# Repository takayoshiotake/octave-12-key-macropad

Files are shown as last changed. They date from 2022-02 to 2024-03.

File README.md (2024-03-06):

# Octave

[][cc-by-sa]

The Octave is a 12-key macropad.
It is primarily designed to be a compact keyboard with support for 12 function keys (F1 - F12).

## Status

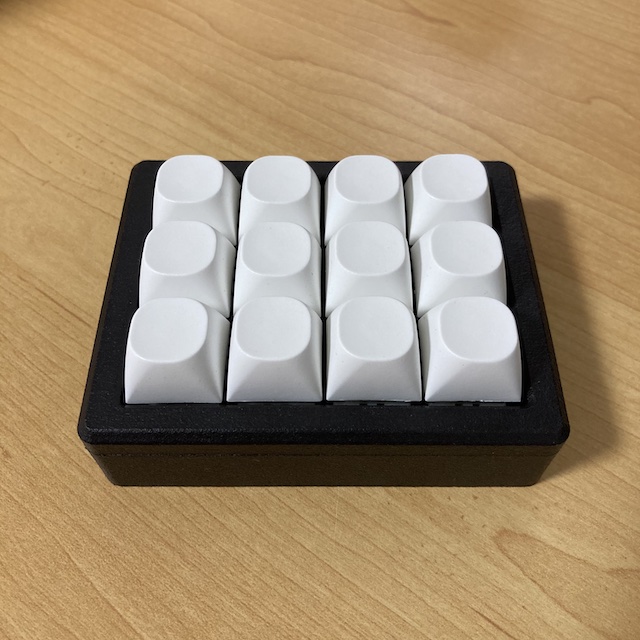
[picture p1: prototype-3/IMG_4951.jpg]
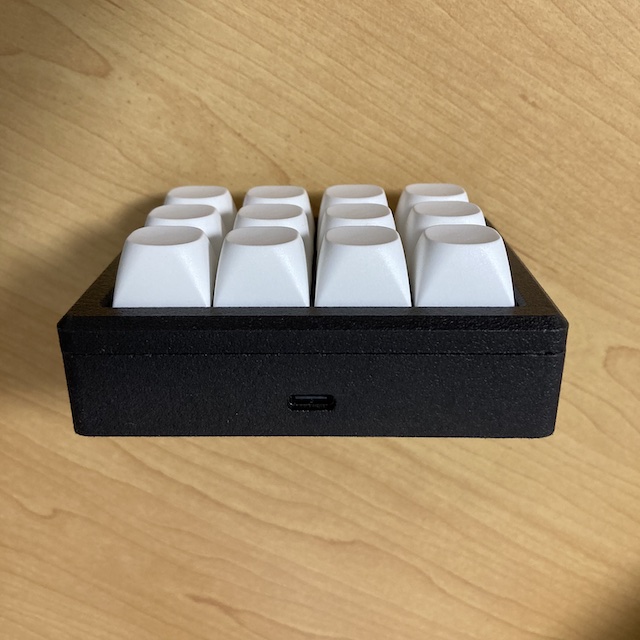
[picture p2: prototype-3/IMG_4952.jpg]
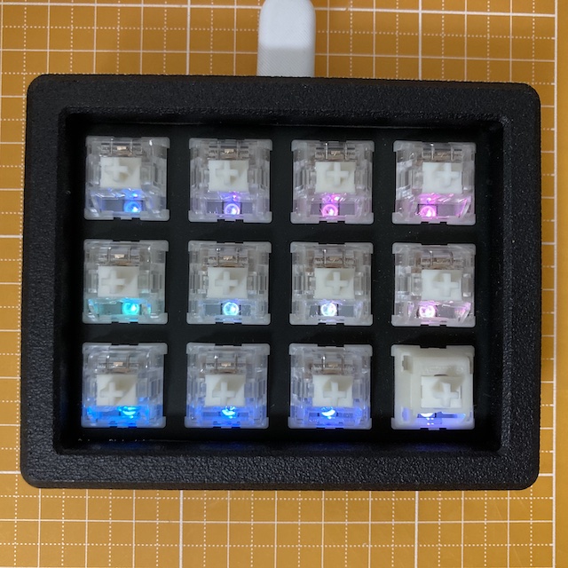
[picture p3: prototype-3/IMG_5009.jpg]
  

- [x] prototype-3.1: Upgrade with LEDs under keys
  - [x] LED Animation
  - [x] PCB: OK!
- [x] prototype-3: Simple design
  - [x] Enclosure: OK!
  - [x] Test: OK!
  - [x] PCB: OK!
- [x] prototype-2: Custom MCU board
  - [x] Consideration
  - [x] Test
  - [x] PCB
- [x] prototype-1

## Specifications

- USB-C (USB2.0, HID)
  - 🔗 <https://pid.codes/1209/8CAE/>
- Hot-swap sockets for MX compatible switches
- Programmable firmware (CircuitPython)

## Layout

📄 [layout/keyboard-layout.png](layout/keyboard-layout.png) (rev.6)

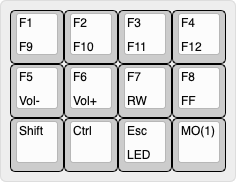
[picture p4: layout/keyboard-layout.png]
keyboard layout


- 12 function keys (F1 - F12)

**RAW data for Keyboard Layout Editor v0.15:**

📄 [layout/keyboard-layout.rawdata.json](layout/keyboard-layout.rawdata.json)

```json
[{f:3},"F1\nF9","F2\nF10","F3\nF11","F4\nF12"],
["F5\nVol-","F6\nVol+","F7\nRW","F8\nFF"],
["Shift","Ctrl","Esc\nLED","MO(1)"]
```

- 🔗 [Keyboard Layout Editor](http://www.keyboard-layout-editor.com/)

## Schematic

📄 [electronics/Octave_Input_PCB.svg](electronics/Octave_Input_PCB.svg) (rev.6.1.2)

schematic svg

I have also designed a custom MCU circuit from prototype-2, the MCU is RP2040 and the software runs on CircuitPython built specifically for it.

📄 [electronics/Octave_Input_PCB/Octave_Input_PCB.kicad_sch](electronics/Octave_Input_PCB/Octave_Input_PCB.kicad_sch)

### Upgrade schematic with LEDs under keys

📄 [electronics/Octave_Input_LED_PCB.svg](electronics/Octave_Input_LED_PCB.svg) (rev.1.0.0)

led schematic svg

📄 [electronics/Octave_Input_PCB/Octave_Input_LED_PCB.kicad_sch](electronics/Octave_Input_PCB/Octave_Input_LED_PCB.kicad_sch)

## PCB

📄 [electronics/Octave_Input_PCB_3D.png](electronics/Octave_Input_PCB_3D.png) (rev.6.1.3)

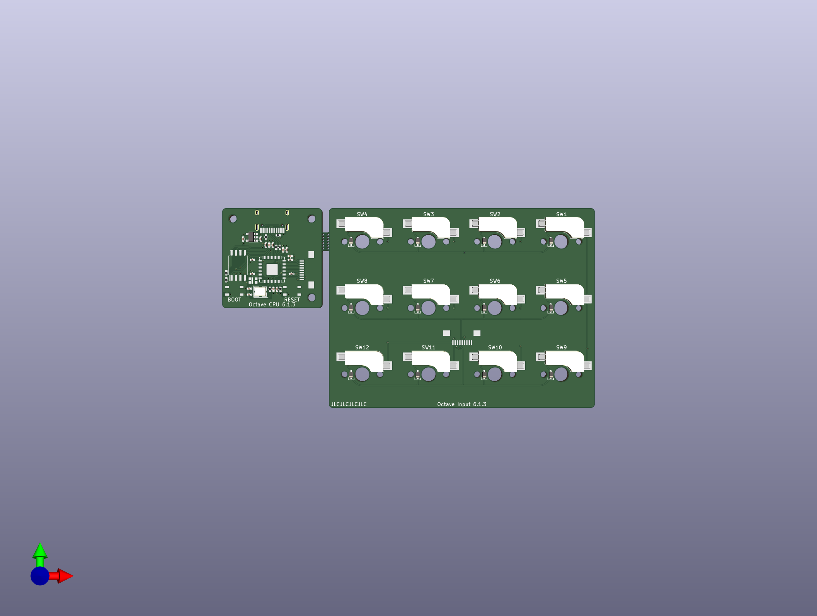
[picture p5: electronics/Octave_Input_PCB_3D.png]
pcb 3d png


📄 [electronics/Octave_Input_PCB/Octave_Input_PCB.kicad_pcb](electronics/Octave_Input_PCB/Octave_Input_PCB.kicad_pcb)

### Upgrade PCB with LEDs under keys

📄 [electronics/Octave_Input_LED_PCB_3D.png](electronics/Octave_Input_LED_PCB_3D.png) (rev.1.0.0)

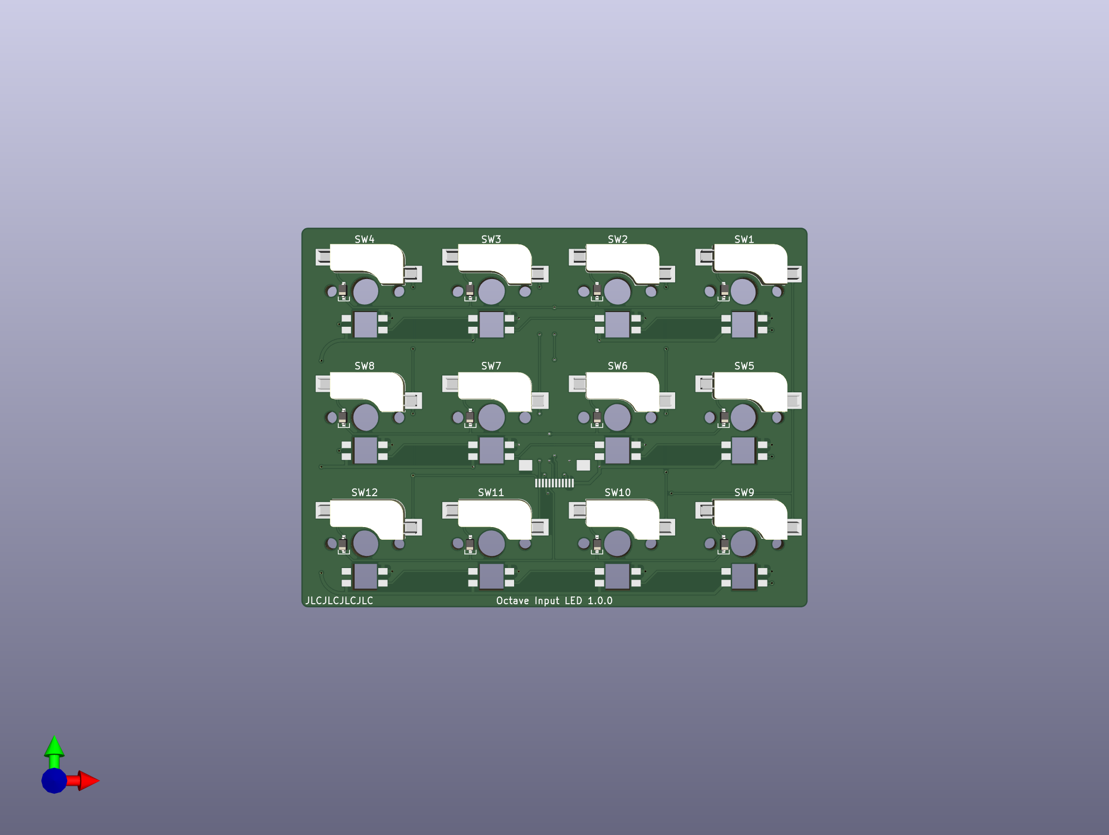
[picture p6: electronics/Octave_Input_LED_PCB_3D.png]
led pcb 3d png


📄 [electronics/Octave_Input_LED_PCB/Octave_Input_LED_PCB.kicad_pcb](electronics/Octave_Input_LED_PCB/Octave_Input_LED_PCB.kicad_pcb)

## CircuitPython

Software for the Octave (prototype-2, prototype-3) runs on CircuitPython.

**Latest:**

- 🔗 [adafruit/circuitpython](https://github.com/adafruit/circuitpython)
  - 🔗 <https://github.com/adafruit/circuitpython/tree/main/ports/raspberrypi/boards/takayoshiotake_octave_rp2040>
- 🔗 [Built UF2](https://adafruit-circuit-python.s3.amazonaws.com/index.html?prefix=bin/takayoshiotake_octave_rp2040/)

**Older:**

- 🔗 [takayoshiotake/circuitpython:7.3.x-board-octave-rp2040](https://github.com/takayoshiotake/circuitpython/tree/7.3.x-board-octave-rp2040)
  - 🔗 <https://github.com/takayoshiotake/circuitpython/tree/c3b4d05dc04d74c6229506215eae799fb23f37ce/ports/raspberrypi/boards/takayoshiotake_octave_rp2040>

- How to build:
  - 🔗 <https://learn.adafruit.com/building-circuitpython/build-circuitpython>
  - 🔗 <https://github.com/takayoshiotake/circuitpython/blob/c3b4d05dc04d74c6229506215eae799fb23f37ce/BUILDING.md>

## Plate

📄 [mechanics/Octave_Plate_3D.png](mechanics/Octave_Plate_3D.png) (rev.1.0.3)

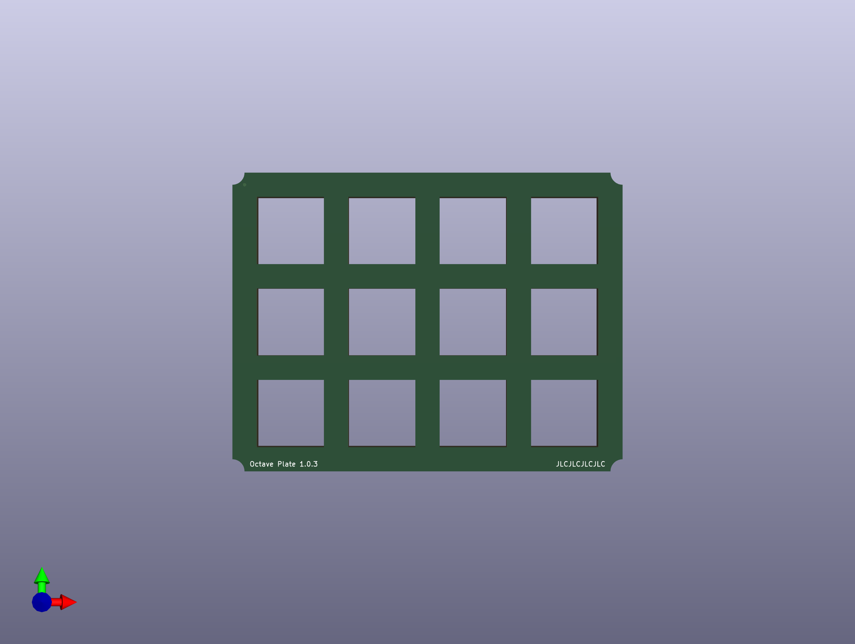
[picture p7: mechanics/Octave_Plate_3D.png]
plate 3d png


📄 [mechanics/Octave_Plate/Octave_Plate.kicad_pcb](mechanics/Octave_Plate/Octave_Plate.kicad_pcb)

## Enclosure

- 📄 [mechanics/Octave_Enclosure-Case.stl](mechanics/Octave_Enclosure-Case.stl) (rev.1.0.0)
- 📄 [mechanics/Octave_Enclosure-Top Frame.stl](mechanics/Octave_Enclosure-Top%20Frame.stl) (rev.1.0.0)

## BOM & Software

🏷 [prototype-3-pcb](https://github.com/takayoshiotake/octave-12-key-macropad/releases/tag/prototype-3-pcb)

| Material | Unit | Designator | Note | JLCPCB Part # |
|-|-:|-|-|-|
| Octave CPU PCB rev.6.1.3 | 1 | n/a | JLCPCB |
| Octave Input PCB rev.6.1.3 *[2]* | 1 | n/a | JLCPCB |
| Octave Plate rev.1.0.3 | 1 | n/a | JLCPCB, Alminium PCB (t=1.6mm) |
| 0151660120 | 1 | n/a | Molex 0.50mm pitch FFC, Type D, 50.80mm, 12 circuits |
| CPG151101S11-2 | 12 | SW1-12 *[2]* | Kailh®︎ hot swap socket (White) |
||
| Octave Enclosure Case rev.1.0.0 | 1 | n/a | JLCPCB, 3D printing (MJF), PA12-HP Nylon |
| Octave Enclosure Top Frame rev.1.0.0 | 1 | n/a | JLCPCB, 3D printing (MJF), PA12-HP Nylon |
| PORON | 4 | n/a | 78mm x 2.5mm (t=1.5mm) |
| PORON | 4 | n/a | 59mm x 2.5mm (t=1.5mm) |
| Screw M2 5mm | 1 | n/a | Hirosugi B-0205 |
| Screw M2 8mm | 4 | n/a | Hirosugi B-0208 |
| Insert nut M2 | 4 | n/a | Hirosugi HSB-203030Z |
| Nut M2 | 1 | n/a | Hirosugi BNT-02-2 |
| Washer M2 | 1 | n/a | Hirosugi BW-0243-03 |
||
| 30pF 0402 | 2 | C15, C16 | PCBA | C1570 |
| 100nF 0402 | 10 | C5-14 | PCBA | C307331 |
| 1uF 0402 | 2 | C3, C4 | PCBA | C52923 |
| 10uF 0402 | 2 | C1, C2 | PCBA | C15525 |
| 1N4148WS | 12 | D1-12 *[2]* | PCBA | C2128 |
| HRO_TYPE-C-31-M-12 | 1 | J1 | PCBA, USB Connector (Type-C) | C165948 |
| JUSHUO_AFC01-S12FCC-00 | 2 | J2, J3 *[2]* | PCBA, FFC Connector (0.50mm pitch, 12 circuits) | C262268 |
| 27Ω 0402 | 2 | R3, R4 | PCBA | C352446 |
| 1KΩ 0402 | 2 | R7, R8 | PCBA | C11702 |
| 5.1KΩ 0402 | 2 | R1, R2 | PCBA | C25905 |
| 10KΩ 0402 | 2 | R5, R6 | PCBA | C25744 |
| AP2112K-3.3 | 1 | U1 | PCBA | C51118 |
| Raspberry Pi RP2040 | 1 | U2 | PCBA | C2040 |
| W25Q64JVSSIQ | 1 | U3 | PCBA | C179171 |
| 12MHz Crystal Resonator SMD-3225 | 1 | Y1 | PCBA, YSX221SL | C9002 |
| SKRPANE010 | 2 | SW21, SW22 | PCBA, Alps Alpine tactile switch | C470426 |
||
| WS2812C-2020-V1 | 1 | LED1 *[1]* | PCBA, NeoPixel | C2976072 |

MEMO: *[1]* To reduce costs, I did not assemble LED1 with PCBA.
MEMO: *[2]* Can be replaced with upgrade parts.

Upgrade parts:

| Material | Unit | Designator | Note | JLCPCB Part # |
|-|-:|-|-|-|
| Octave Input LED PCB rev.1.0.0 | 1 | n/a | JLCPCB |
| CPG151101S11-2 | 12 | SW1-12 | Kailh®︎ hot swap socket (White) |
||
| 1N4148WS | 12 | D1-12 | PCBA | C2128 |
| JUSHUO_AFC01-S12FCC-00 | 1 | J3 | PCBA, FFC Connector (0.50mm pitch, 12 circuits) | C262268 |
||
| WS2812B-Mini-V3 | 12 | LED201-0212 | NeoPixel |

- Octave CPU PCB rev.6.1.3, Octave Input PCB rev.6.1.3 (PCBA)

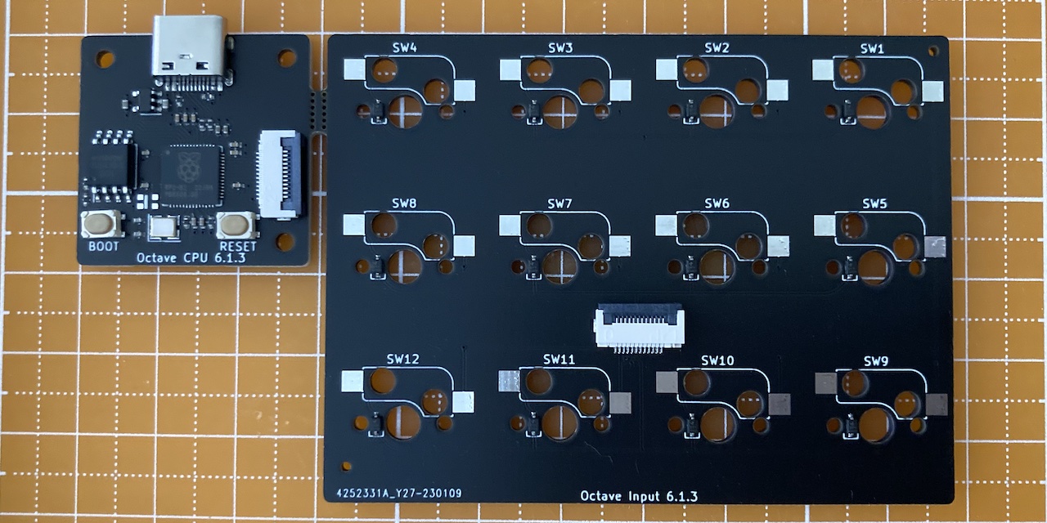
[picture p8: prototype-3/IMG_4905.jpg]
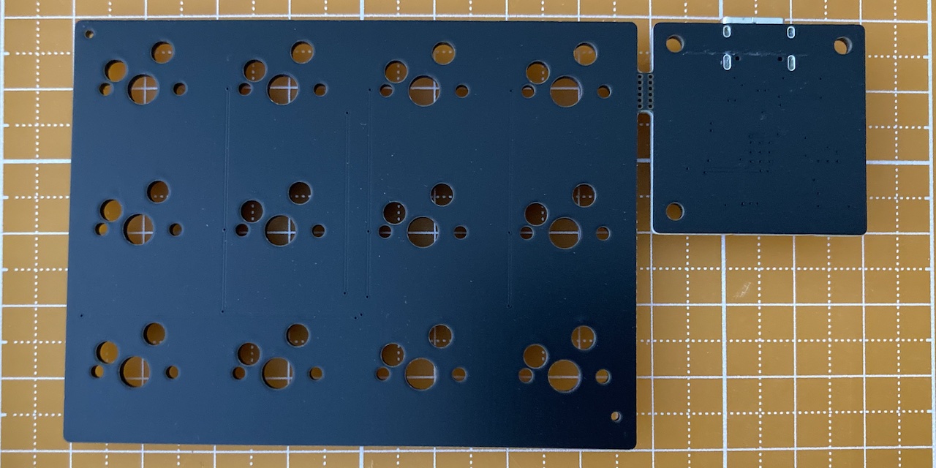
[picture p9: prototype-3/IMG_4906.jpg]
     

- Octave Input LED PCB rev.1.0.0 (Upgrade)

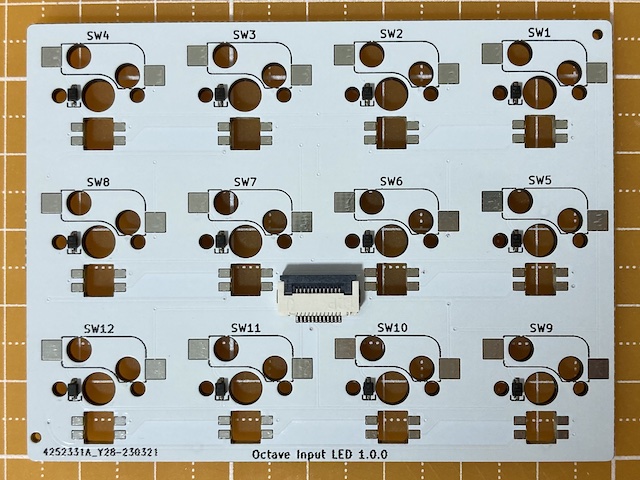
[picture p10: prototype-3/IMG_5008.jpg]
    

- Octave Plate rev.1.0.3

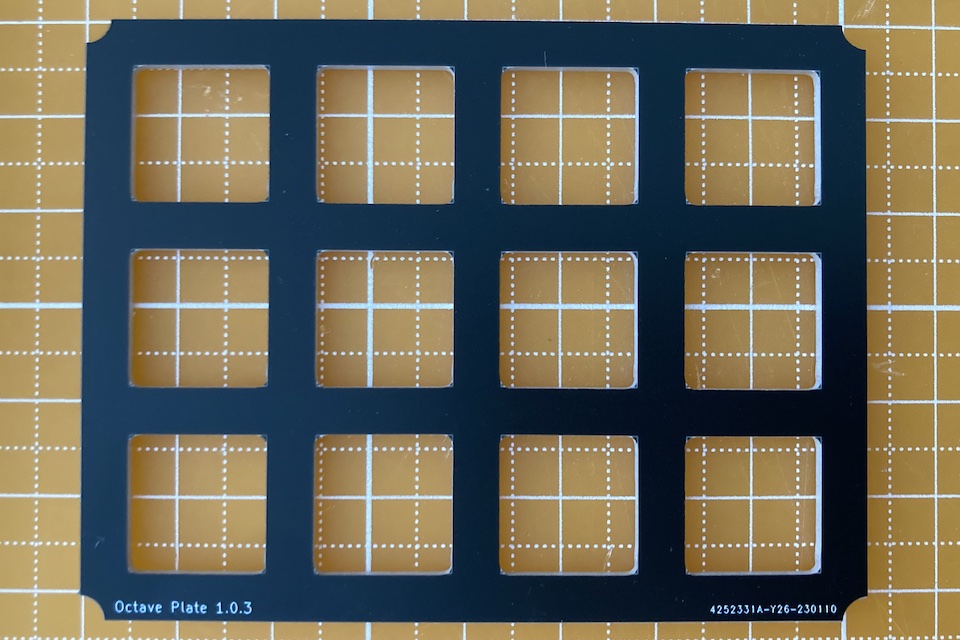
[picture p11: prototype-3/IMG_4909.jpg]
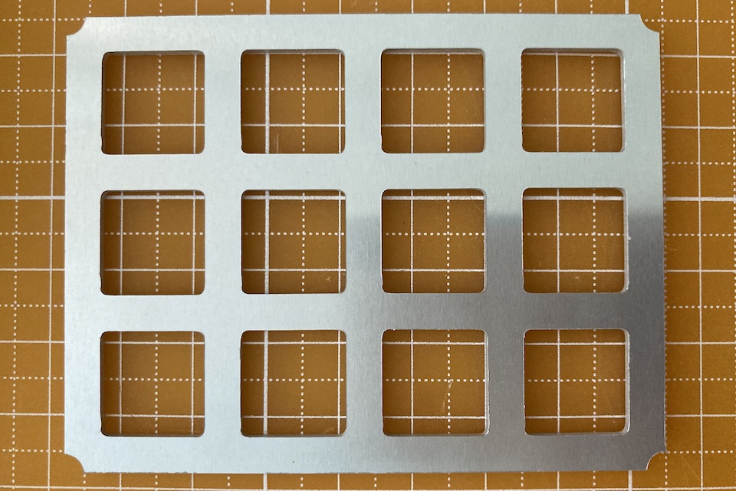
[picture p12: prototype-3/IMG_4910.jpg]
     

- Assembly

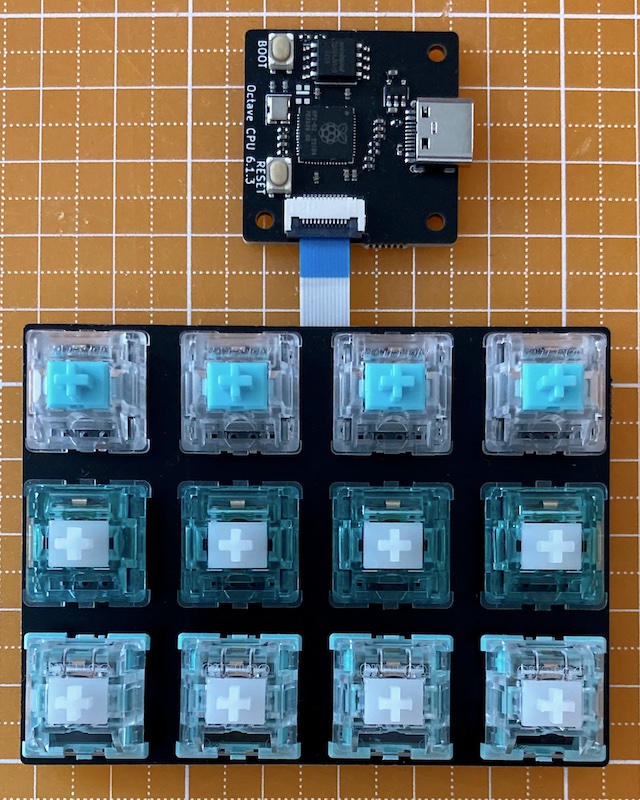
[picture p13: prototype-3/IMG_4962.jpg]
    
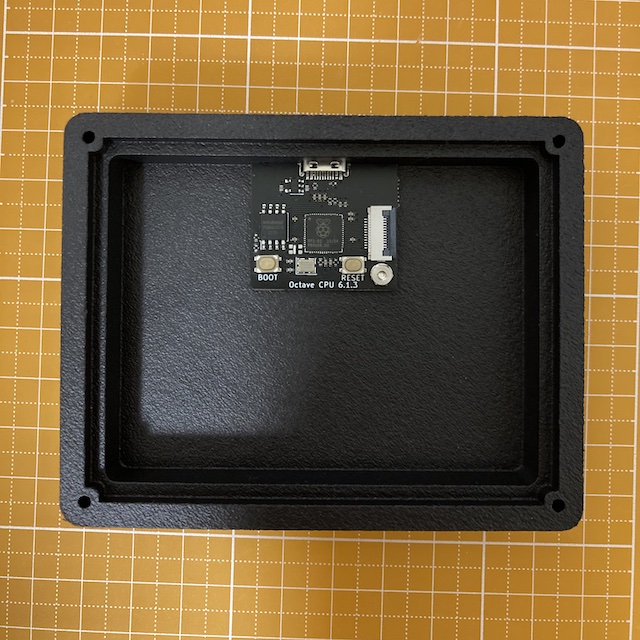
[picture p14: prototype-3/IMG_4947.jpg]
    
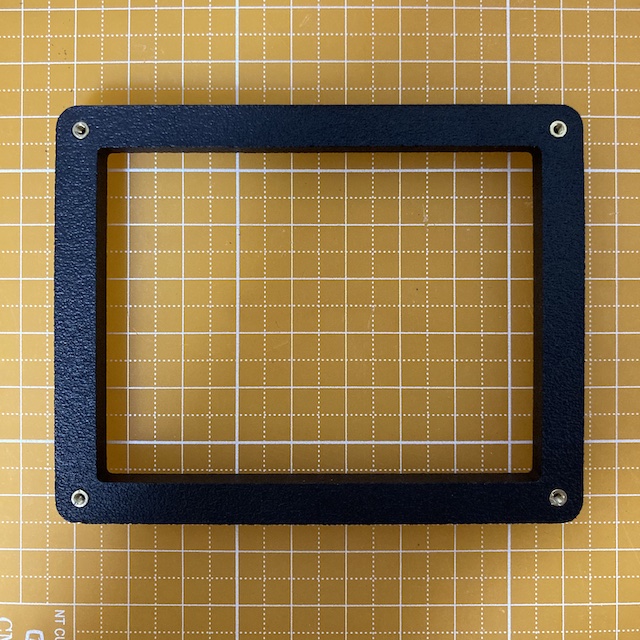
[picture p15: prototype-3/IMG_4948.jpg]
    

### Software

- [Software](software/README.md)

### History

- [[Closed] prototype-2](prototype-2/README.md)
- [[Closed] prototype-1](prototype-1/README.md)

## License

This work is licensed under a
[Creative Commons Attribution-ShareAlike 4.0 International License][cc-by-sa].

[][cc-by-sa]

[cc-by-sa]: http://creativecommons.org/licenses/by-sa/4.0/
[cc-by-sa-image]: https://licensebuttons.net/l/by-sa/4.0/88x31.png
[cc-by-sa-shield]: https://img.shields.io/badge/license-CC%20BY--SA%204.0-lightgrey.svg

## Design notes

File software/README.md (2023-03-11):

# README

## Setup

1. Install CircuitPython 8.0.x
    1. Connect Octave via USB
    2. Reboot Octave by holding down BOOT and pressing RESET
    3. Copy (drag & drop) uf2 to RPI-RP2
        - 📄 [adafruit-circuitpython-takayoshiotake_octave_rp2040-en_US-8.0.3.uf2](../circuitpython-bin/adafruit-circuitpython-takayoshiotake_octave_rp2040-en_US-8.0.3.uf2)

2. Renaming CIRCUITPY to OCTAVE_CP

    - 🔗 [https://learn.adafruit.com/welcome-to-circuitpython/renaming-circuitpy](https://learn.adafruit.com/welcome-to-circuitpython/renaming-circuitpy)

## Install packages

```shell-session
% poetry install
% poetry shell
(.venv) % circup --path /Volumes/OCTAVE_CP install -r requirements.txt
```

Alternatively:

```shell-session
% cp -r lib /Volumes/OCTAVE_CP/
```

## Upload

```shell-session
% cp boot.py code.py /Volumes/OCTAVE_CP/
% cp -r octave_pcb /Volumes/OCTAVE_CP/
```

MEMO: After uploading boot.py, you need to hold down SW1 to boot to enable the USB drive.

## Note

🔗 <https://learn.adafruit.com/circuitpython-essentials/circuitpython-resetting>

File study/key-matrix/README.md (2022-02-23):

# key-matrix

This is an example of a 4x4 key matrix covering 14 keys. 8 GPIOs can be used to scan up to 16 switches.

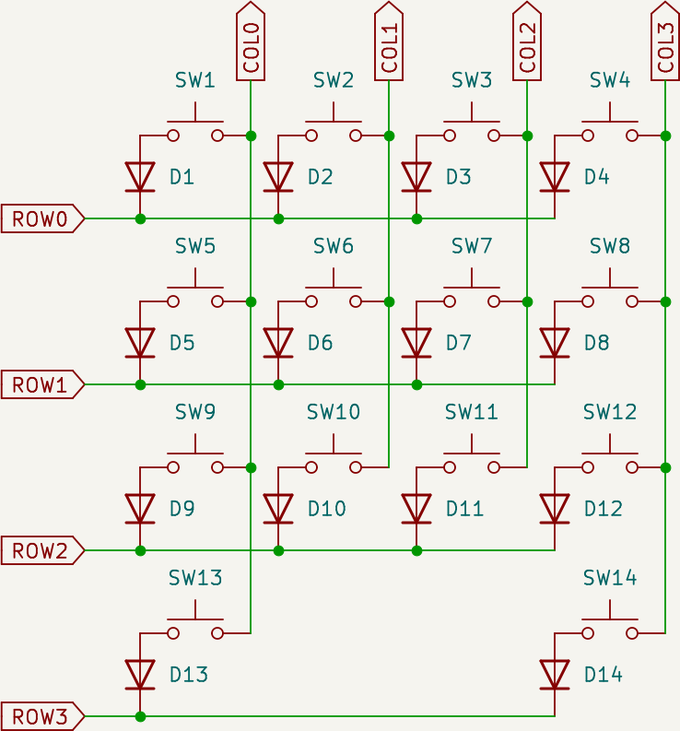
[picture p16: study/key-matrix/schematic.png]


Although omitted in the schematic, `COL0` to `COL3` are assumed to be connected to the pulled-up GPIO input pins, and `ROW0` to `ROW3` are assumed to be connected to the GPIO output pins.

To scan whether `SW1` to `SW4` are ON or OFF, set `ROW0` to Low and `ROW1` to `ROW3` to High, and read whether `COL0` to `COL3` are Low or High.

For example, when `SW2`, `SW3`, `SW7`, and `SW8` are pressed, `COL1` and `COL2` are set to Low, but `COL0` and `COL3` remains High.

In this case, current will flow from `COL1` and `COL2` to `ROW0`, but no current will flow between `COL2`, `COL3` and `ROW1` due to D7 and D8.

In this circuit, matrix scan is done row by row.

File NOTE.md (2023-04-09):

# NOTE

- Hot-swap sockets for MX compatible switches
  - Kailh CPG151101S11-x
    - <http://www.kailh.com/en/Products/Ks/HPC/>

- Incremental encoder with push momentary switch
  - Bourns PEC11R-4xxxF-Sxxxx
    - <https://www.bourns.com/products/encoders/contacting-encoders/product/PEC11R>
  - Bourns PEC12R-4xxxF-Sxxxx
    - <https://www.bourns.com/products/encoders/contacting-encoders/product/PEC12R>

- Stick Controller
  - Alps Alpine RKJXV/RKJX2 Series - RKJXV122400R
    - <https://tech.alpsalpine.com/prod/e/html/multicontrol/potentiometer/rkjxk/rkjxk_list.html>

- Tactile Switch
  - Alps Alpine SKRP Series - SKRPANE010, SKRPABE010
    - <https://tech.alpsalpine.com/prod/e/html/tact/surfacemount/skrp/skrp_list.html>

- Programmable firmware (CircuitPython)
  - <https://circuitpython.org/>
  - <https://docs.circuitpython.org/en/latest/BUILDING.html>

- Adafruit QT Py RP2040
  - <https://www.adafruit.com/product/4900>
  - <https://circuitpython.org/board/adafruit_qtpy_rp2040/>

- Pimoroni PGA2040
  - <https://shop.pimoroni.com/products/pga2040?variant=39359629656147>
  - <https://circuitpython.org/board/pimoroni_pga2040/>

- Seeed XIAO RP2040
  - <https://www.seeedstudio.com/XIAO-RP2040-v1-0-p-5026.html>

- RP2040
  - <https://datasheets.raspberrypi.com/rp2040/hardware-design-with-rp2040.pdf>

- Serial NOR Flash
  - Windbond W25Q64JVSSIQ
    - <https://www.winbond.com/hq/product/code-storage-flash-memory/serial-nor-flash/index.html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>

- USB-C
  - To use USB2.0 with USB-C, the CC1 and CC2 pins need pull down 5.1K.
    - <https://www.microchip.com/en-us/application-notes/an1914>
  - Molex 1054500101
    - <https://www.molex.com/molex/products/part-detail/io_connectors/1054500101>
  - Korean Hroparts Electronics TYPE-C-31-M-12
    - <http://www.krhro.com/USBjack/20180124/764.html>

- Power
  - Diodes AP2112K-3.3
    - <https://www.diodes.com/part/view/AP2112/>

- Crystal Resonator
  - Yangxing Tech YSX321SL 12Mhz (SMD3225-4)
    - <https://www.yangxing.hk/products-detail/ysx321sl>
  - `CL = (C1 * C2) / (C1 + C2) + C(~5pF) => C1 = C2 = (CL - 5pF) * 2`
    - `CL = 20pF => C = 30pF`

- LED
  - WS2812C-2020-V1
    - <http://www.world-semi.com/solution/list-4-1.html>
    - <https://lcsc.com/product-detail/Light-Emitting-Diodes-LED_Worldsemi-WS2812C-2020-V1_C2976072.html>

- General-purpose case
  - WSC10-14-5W
    - <https://www.takachi-el.co.jp/products/WSC>

- FFC
  - Molex 15166012x (0.5mm pitch, 12 circuits, Type D)
    - <https://www.molex.com/molex/products/part-detail/cable/0151660122>
    - <https://www.molex.com/molex/products/part-detail/cable/0151660126>

## PCB

- JLCPCB
  - RP2040: <https://jlcpcb.com/parts/componentSearch?isSearch=true&searchTxt=RP2040>
  - ATMEGA32U4-MU: <https://jlcpcb.com/parts/componentSearch?isSearch=true&searchTxt=ATMEGA32U4-MU>
  - AFC01-S08FCC-00: <https://jlcpcb.com/parts/componentSearch?isSearch=true&searchTxt=AFC01-S08FCC-00>
  - AFC01-S12FCC-00: <https://jlcpcb.com/parts/componentSearch?isSearch=true&searchTxt=AFC01-S12FCC-00>
  - <https://support.jlcpcb.com/article/194-how-to-generate-gerber-and-drill-files-in-kicad-6>

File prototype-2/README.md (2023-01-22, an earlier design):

# prototype-2

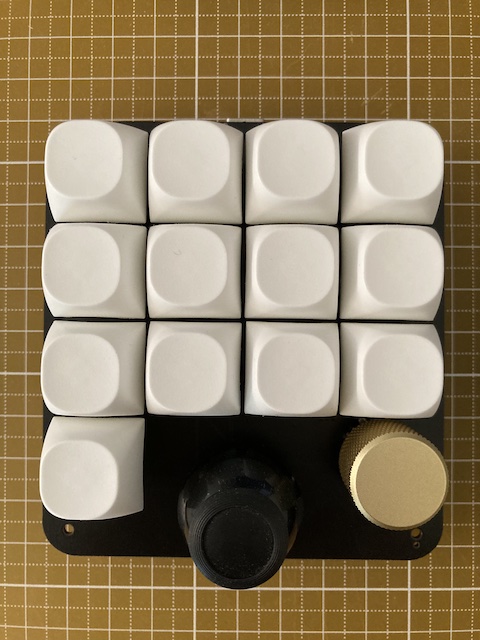
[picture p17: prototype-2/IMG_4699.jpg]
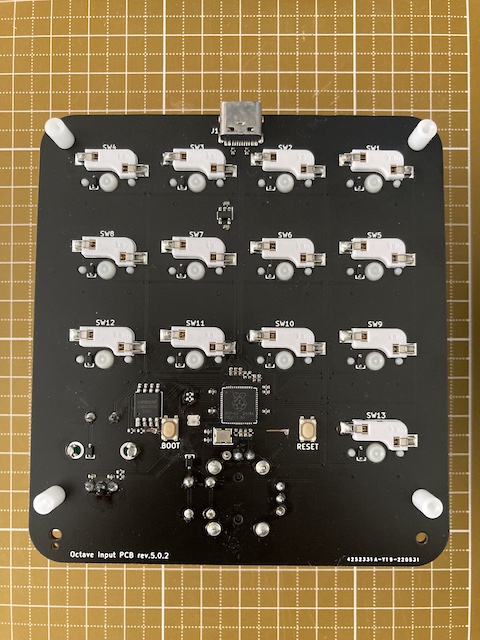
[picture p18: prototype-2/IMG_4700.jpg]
 

## BOM

**PCB:**

🏷 [prototype-2-pcb](https://github.com/takayoshiotake/octave-12-key-macropad/releases/tag/prototype-2-pcb)

| Material | Unit | Designator | Note | JLCPCB Part # |
|-|-:|-|-|-|
| Octave Input PCB rev.5.0.2 | 1 | n/a | JLCPCB |
| 30pF 0402 | 2 | C15, C16 | PCBA | C1570 |
| 10nF 0402 | 2 | C21, C22 | PCBA | C15195 |
| 100nF 0402 | 10 | C5-14 | PCBA | C307331 |
| 1uF 0402 | 2 | C3, C4 | PCBA | C52923 |
| 10uF 0402 | 2 | C1, C2 | PCBA | C15525 |
| 1N4148WS | 15 | D1-15 | PCBA | C2128 |
| HRO_TYPE-C-31-M-12 | 1 | J1 | PCBA, USB Connector (Type-C) | C165948 |
| WS2812C-2020-V1 | 1 | LED1 | PCBA, NeoPixel | C2976072 |
| 27Ω 0402 | 2 | R3, R4 | PCBA | C352446 |
| 1KΩ 0402 | 2 | R7, R8 | PCBA | C11702 |
| 5.1KΩ 0402 | 2 | R1, R2 | PCBA | C25905 |
| 10KΩ 0402 | 4 | R5, R6, R12, R14 | PCBA | C25744 |
| 100KΩ 0402 | 2 | R11, R13 | PCBA | C25086 |
| AP2112K-3.3 | 1 | U1 | PCBA | C51118 |
| Raspberry Pi RP2040 | 1 | U2 | PCBA | C2040 |
| W25Q64JVSSIQ | 1 | U3 | PCBA | C179171 |
| 12MHz Crystal Resonator SMD-3225 | 1 | Y1 | PCBA, YSX221SL | C9002 |
| CPG151101S11-2 | 13 | SW1-13 | Kailh®︎ hot swap socket (White) |
| RKJXV122400R | 1 | SW14 | Alps Alpine stick controller |
| PEC12R-4217F-S0024-ND | 1 | SW15 | Bourns incremental encoder |
| SKRPANE010 | 2 | SW21, SW22 | PCBA, Alps Alpine tactile switch | C470426 |

## CircuitPython

Software for the Octave (prototype-2) runs on CircuitPython.
You can fetch the CircuitPython source code for the Octave from the following GitHub repo.

**Stable:**

- 🔗 [takayoshiotake/circuitpython:7.3.x-board-octave-rp2040](https://github.com/takayoshiotake/circuitpython/tree/7.3.x-board-octave-rp2040)
  - <https://github.com/takayoshiotake/circuitpython/tree/c3b4d05dc04d74c6229506215eae799fb23f37ce/ports/raspberrypi/boards/takayoshiotake_octave_rp2040>

**Latest:**

- 🔗 [adafruit/circuitpython](https://github.com/adafruit/circuitpython)
  - <https://github.com/adafruit/circuitpython/tree/main/ports/raspberrypi/boards/takayoshiotake_octave_rp2040>
- 🔗 [Built UF2](https://adafruit-circuit-python.s3.amazonaws.com/index.html?prefix=bin/takayoshiotake_octave_rp2040/)

## Software

🏷 [9bc4500: https://github.com/takayoshiotake/octave-12-key-macropad/tree/40bdf7dd3696c3ced7790cf87acc5dc2551b9874/software](https://github.com/takayoshiotake/octave-12-key-macropad/tree/40bdf7dd3696c3ced7790cf87acc5dc2551b9874/software)

## Issues

- [x] Fatal: SW21 and SW22 do not work.
  ↪︎ BOOT, RESET works when manually shorted to GND by wire.
  ↪︎ Fixed schematics and PCB in rev.5.0.3
- [x] Fatal: Rotation cannot be detected because SingalA and SignalB do not go to Low level due to the value of R11, R13 in the schematic rev.5.0.2.
  ↪︎ It can be solved by removing R1 and R3 and using pull-up of RP2040 instead, or use a **small** value such as 1K for R11 and R13.
  ↪︎ Fixed schematics and PCB in rev.5.0.4
- [x] The incremental encoder and stick controller are difficult to operate with this placement on the PCB.
  ↪︎ These input devices are not considered important and will be removed in the next version. It should be simple.
- [x] Custom MCU boards are expensive to manufacture and require a lot of work, including the need for USB VID/PID. Also, the board is larger due to the USB-C connector.
  ↪︎ It seems that it would be better to separate the IO board from the MCU board. However, if they are connected with pin headers, it will be difficult to design a housing as in Prototype 1, so I think it is better to connect them with cables.
  ↪︎ Considered in next prototype.

## Results

Remove the incremental encoders and stick controller.
And for the next prototype, I will consider whether to divide the PCB into an MCU board and an IO board, and whether to adopt a custom MCU board.

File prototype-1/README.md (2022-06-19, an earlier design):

# [Closed] prototype-1

## BOM

**PCB:**

| Material | Unit | Designator | Note |
|-|-:|-|-|
| Octave Input PCB rev.2.1 | 1 | n/a | JLCPCB |
| 0.01uF 0805(2012 Metric) | 2 | C1,C2 | PCBA |
| 1N4148WS | 14 | D1-14 | PCBA |
| 10KΩ 0805(2012 Metric) | 4 | R1-4 | PCBA |
| XIAO RP2040 | 1 | U1 | Seeed |
| 1x7-pin header | 2 | U1 | included with XIAO RP2040 |
| CPG151101S11-2 | 13 | SW1-12, SW14 | Kailh®︎ hot swap socket |
| PEC12R-4217F-S0024-ND | 1 | SW13 | Bourns incremental encoder |
| Boba U4 (68g) | 13 | (SW1-12, SW14) | Gazzew silent tactile keyboard switch |
| GLO-ACC-P75-RK-G | 1 | (SW13) | Glorious rotary knob for GMMK Pro (Gold) |

**Enclosure:**

| Material | Unit | Note |
|-|-:|-|
| WSC10-14-5W | 1 | TAKACHI Sloped plastic enclosure |
| M2.3 x6mm self-tapping screw  | 4 |  |

- Octave Input PCB rev.2.1

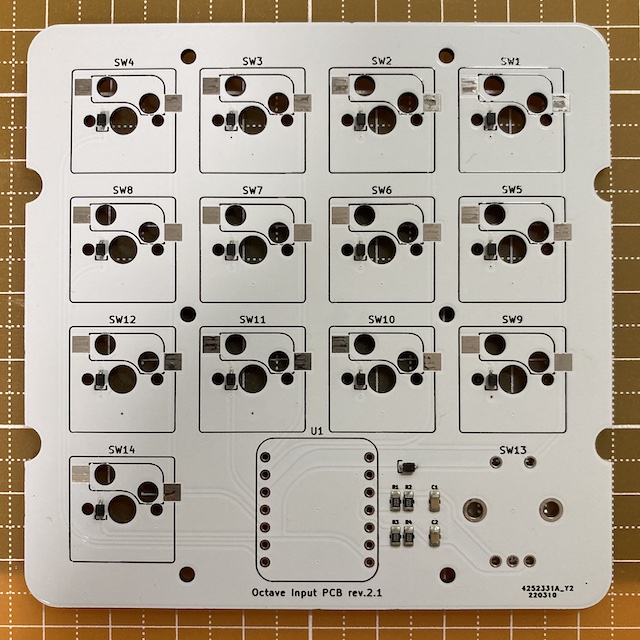
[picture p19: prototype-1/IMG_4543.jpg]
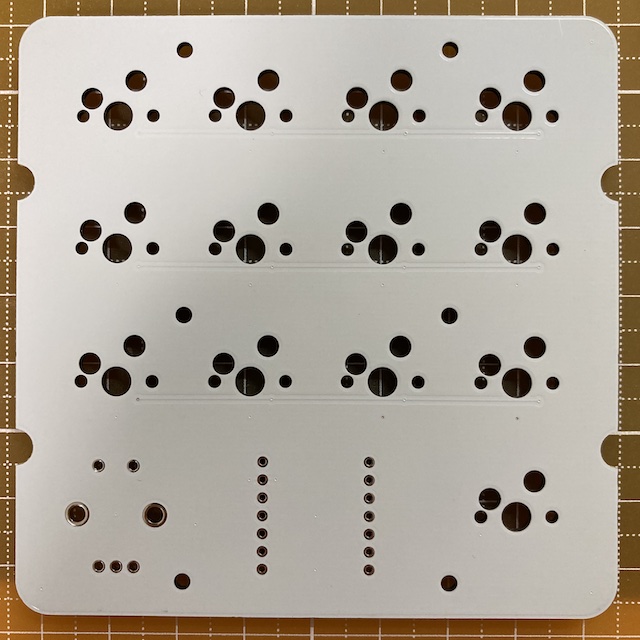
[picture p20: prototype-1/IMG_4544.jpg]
     

- Octave Input PCB rev.2.1 (Assembled)

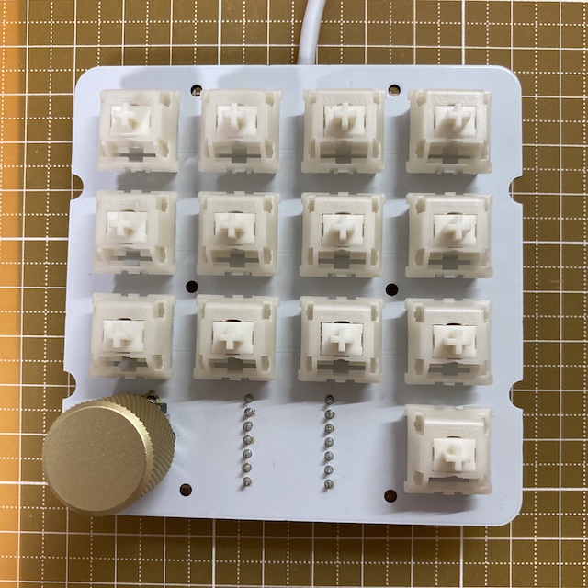
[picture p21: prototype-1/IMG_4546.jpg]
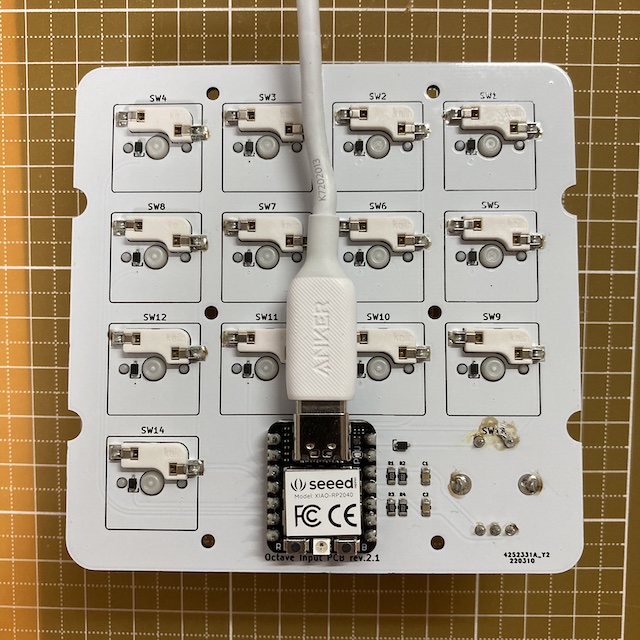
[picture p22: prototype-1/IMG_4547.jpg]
     

- 1x7-pin header (adjusted length)

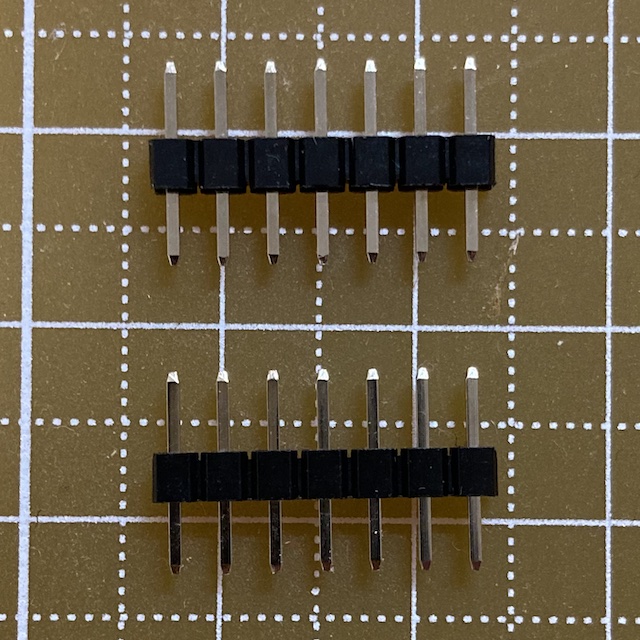
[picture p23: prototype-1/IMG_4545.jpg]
    

- Enclosure

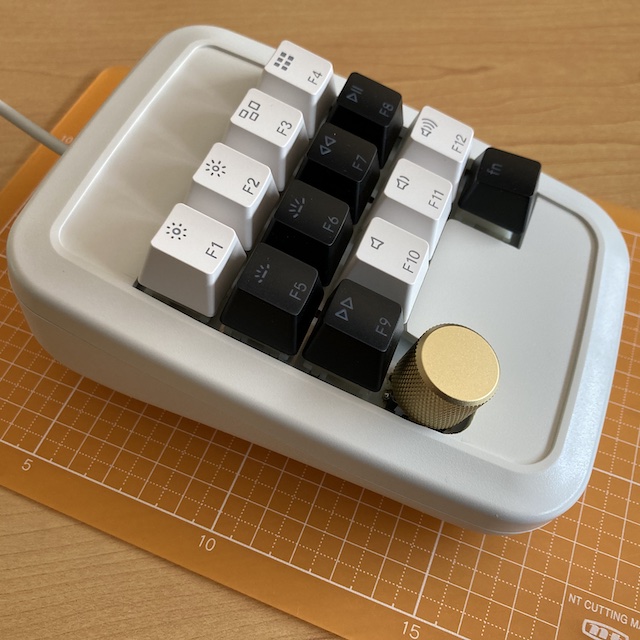
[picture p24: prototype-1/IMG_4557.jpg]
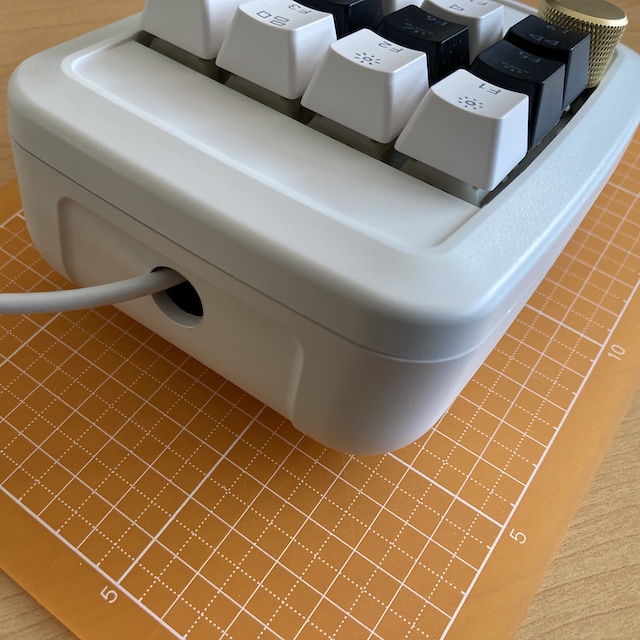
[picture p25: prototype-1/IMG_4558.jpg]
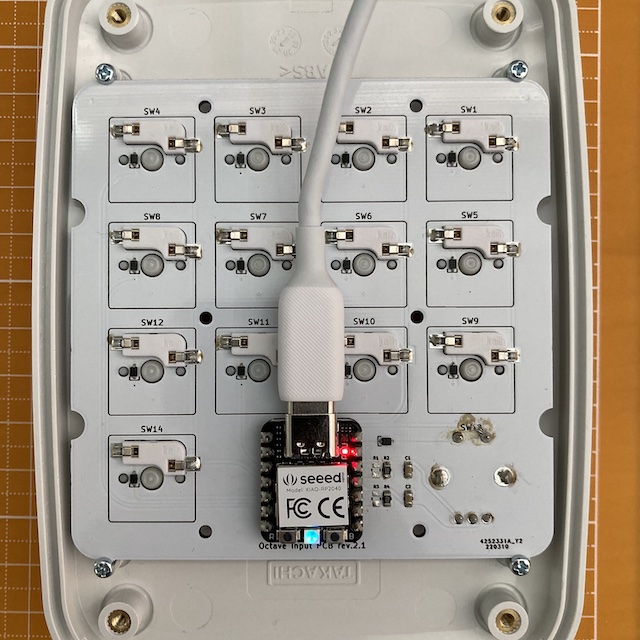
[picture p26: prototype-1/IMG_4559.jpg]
      

## Software

- 📄 [software/README.md](software/README.md)

## Issues

- [x] Some pin names in U1 of schematic rev.2 are incorrect (D8-11 --> D7-10)
    ↪︎ Fixed in rev.3
- [x] Pay attention to the mounting surface of SW13
    ↪︎ I'll be very careful next time...
- [x] The XIAO RP2040's POWER LED (RED) cannot be turned off because it cannot be controlled.
    ↪︎ no problem
- [x] Fatal: Rotation cannot be detected because SingalA and SignalB do not go to Low level due to the value of R1-R4 in the schematic rev.2.
    ↪︎ It can be solved by removing R1 and R3 and using pull-up of RP2040 instead, or use a large value such as 100K for R1 and R3.
    ↪︎ Fixed in rev.3

The following issues are carried over to the next prototype.

- In PCB rev.2.1, col0 will not work if the through hole of pin1 of SW13 fails.
    ↪︎ Improve routing
- The push switch of PEC12R-4217F-S0024-ND is clicky and heavy and loud.
- A specially designed enclosure is required.
    ↪︎ U1 takes up a lot of space.
    ↪︎ The only way seems to be to design a dedicated MCU circuit.

## Results

The combination of PEC12R-4217F-S0024-ND and GLO-ACC-P75-RK-G fits perfectly.
However, although the PEC12R-4217F-S0024-ND is great as a rotary encoder, it has a heavy click feeling and a loud sound, so I would like to find an alternative.

I think the most important issue is that the USB cable must be connected inside the enclosure.
It seems necessary to design the MCU circuit in the next prototype.

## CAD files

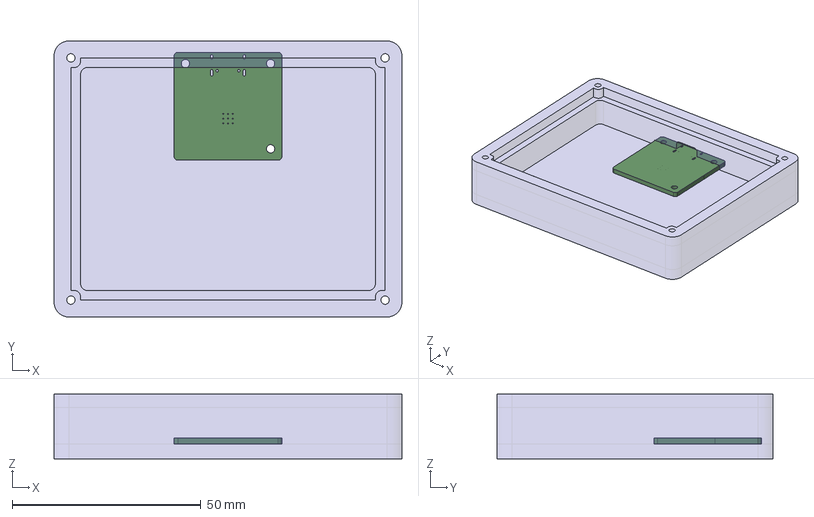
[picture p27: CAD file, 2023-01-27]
mechanics/Octave_Enclosure.FCStd
92.2 x 73.2 x 17.2 mm
Octave_CPU_PCB
Case

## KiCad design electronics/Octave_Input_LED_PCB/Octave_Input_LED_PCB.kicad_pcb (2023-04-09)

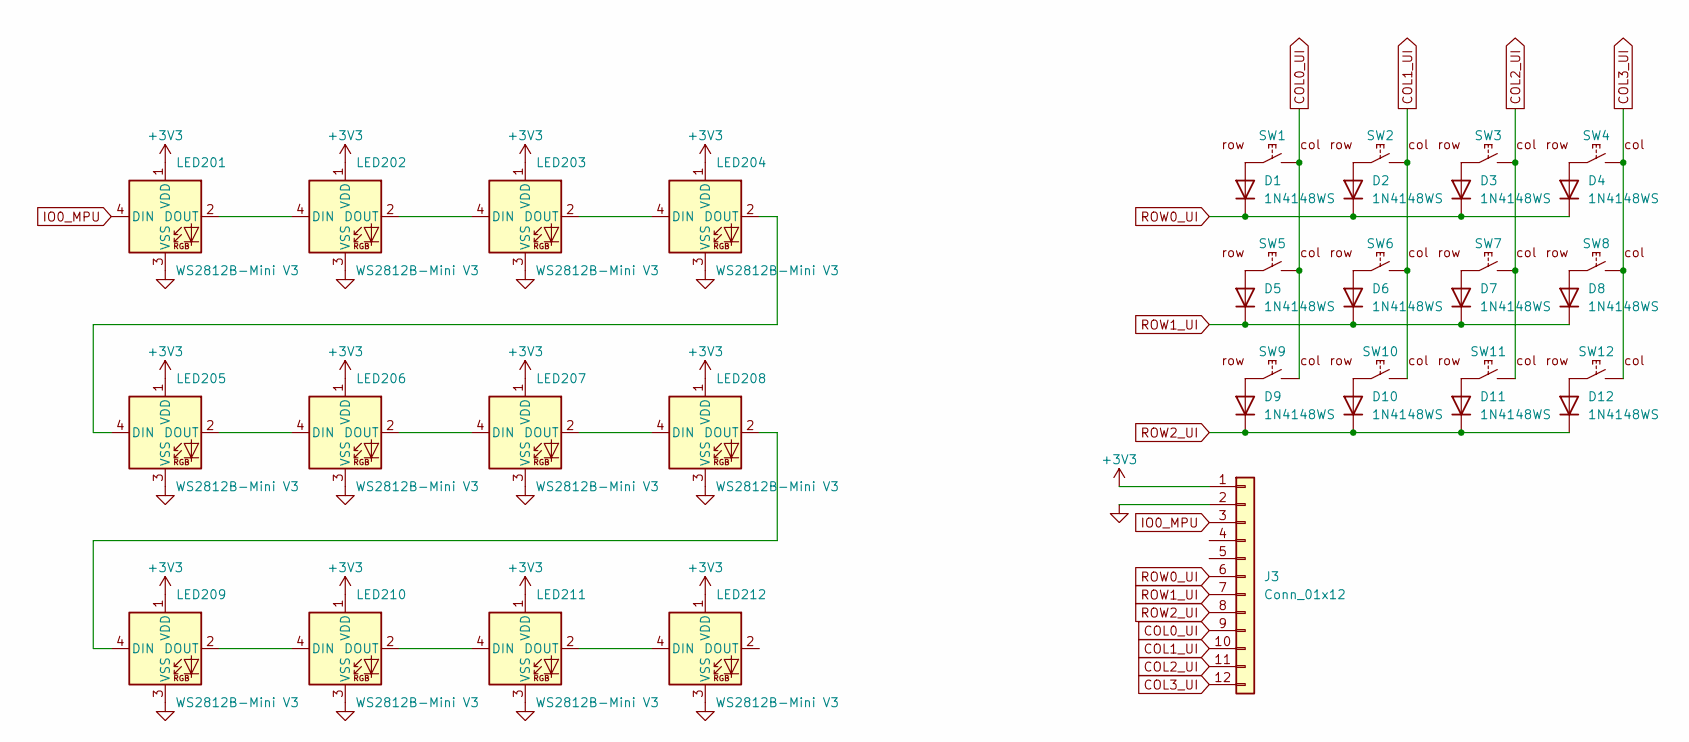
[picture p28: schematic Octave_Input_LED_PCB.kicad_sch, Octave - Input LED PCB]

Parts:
D1, D2, D3, D4, D5, D6, D7, D8, D9, D10, D11, D12: 1N4148WS; D_SOD-323F
J3: Conn_01x12; JUSHUO_AFC01-S12FCC-00
LED201, LED202, LED203, LED204, LED205, LED206, LED207, LED208, LED209, LED210, LED211, LED212: WS2812B-Mini V3; WS2812B-Mini_Inverted
SW1, SW2, SW3, SW4, SW5, SW6, SW7, SW8, SW9, SW10, SW11, SW12: SW_Hot_Swap_Socket; Hot_Swap_Socket_CPG151101S11

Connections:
+3V3: J3.1, LED201.1 (VDD), LED202.1 (VDD), LED203.1 (VDD), LED204.1 (VDD), LED205.1 (VDD), LED206.1 (VDD), LED207.1 (VDD), LED208.1 (VDD), LED209.1 (VDD), LED210.1 (VDD), LED211.1 (VDD), LED212.1 (VDD)
COL0_UI: J3.9, SW1.2, SW5.2, SW9.2
COL1_UI: J3.10, SW2.2, SW6.2, SW10.2
COL2_UI: J3.11, SW3.2, SW7.2, SW11.2
COL3_UI: J3.12, SW4.2, SW8.2, SW12.2
GND: J3.2, LED201.3 (VSS), LED202.3 (VSS), LED203.3 (VSS), LED204.3 (VSS), LED205.3 (VSS), LED206.3 (VSS), LED207.3 (VSS), LED208.3 (VSS), LED209.3 (VSS), LED210.3 (VSS), LED211.3 (VSS), LED212.3 (VSS)
IO0_MPU: J3.3, LED201.4 (DIN)
unnamed: D1.2 (A), SW1.1
unnamed: D2.2 (A), SW2.1
unnamed: D3.2 (A), SW3.1
unnamed: D4.2 (A), SW4.1
unnamed: D5.2 (A), SW5.1
unnamed: D6.2 (A), SW6.1
unnamed: D7.2 (A), SW7.1
unnamed: D8.2 (A), SW8.1
unnamed: D9.2 (A), SW9.1
unnamed: D10.2 (A), SW10.1
unnamed: D11.2 (A), SW11.1
unnamed: D12.2 (A), SW12.1
unnamed: LED201.2 (DOUT), LED202.4 (DIN)
unnamed: LED202.2 (DOUT), LED203.4 (DIN)
unnamed: LED203.2 (DOUT), LED204.4 (DIN)
unnamed: LED204.2 (DOUT), LED205.4 (DIN)
unnamed: LED205.2 (DOUT), LED206.4 (DIN)
unnamed: LED206.2 (DOUT), LED207.4 (DIN)
unnamed: LED207.2 (DOUT), LED208.4 (DIN)
unnamed: LED208.2 (DOUT), LED209.4 (DIN)
unnamed: LED209.2 (DOUT), LED210.4 (DIN)
unnamed: LED210.2 (DOUT), LED211.4 (DIN)
unnamed: LED211.2 (DOUT), LED212.4 (DIN)
ROW0_UI: D1.1 (K), D2.1 (K), D3.1 (K), D4.1 (K), J3.6
ROW1_UI: D5.1 (K), D6.1 (K), D7.1 (K), D8.1 (K), J3.7
ROW2_UI: D9.1 (K), D10.1 (K), D11.1 (K), D12.1 (K), J3.8

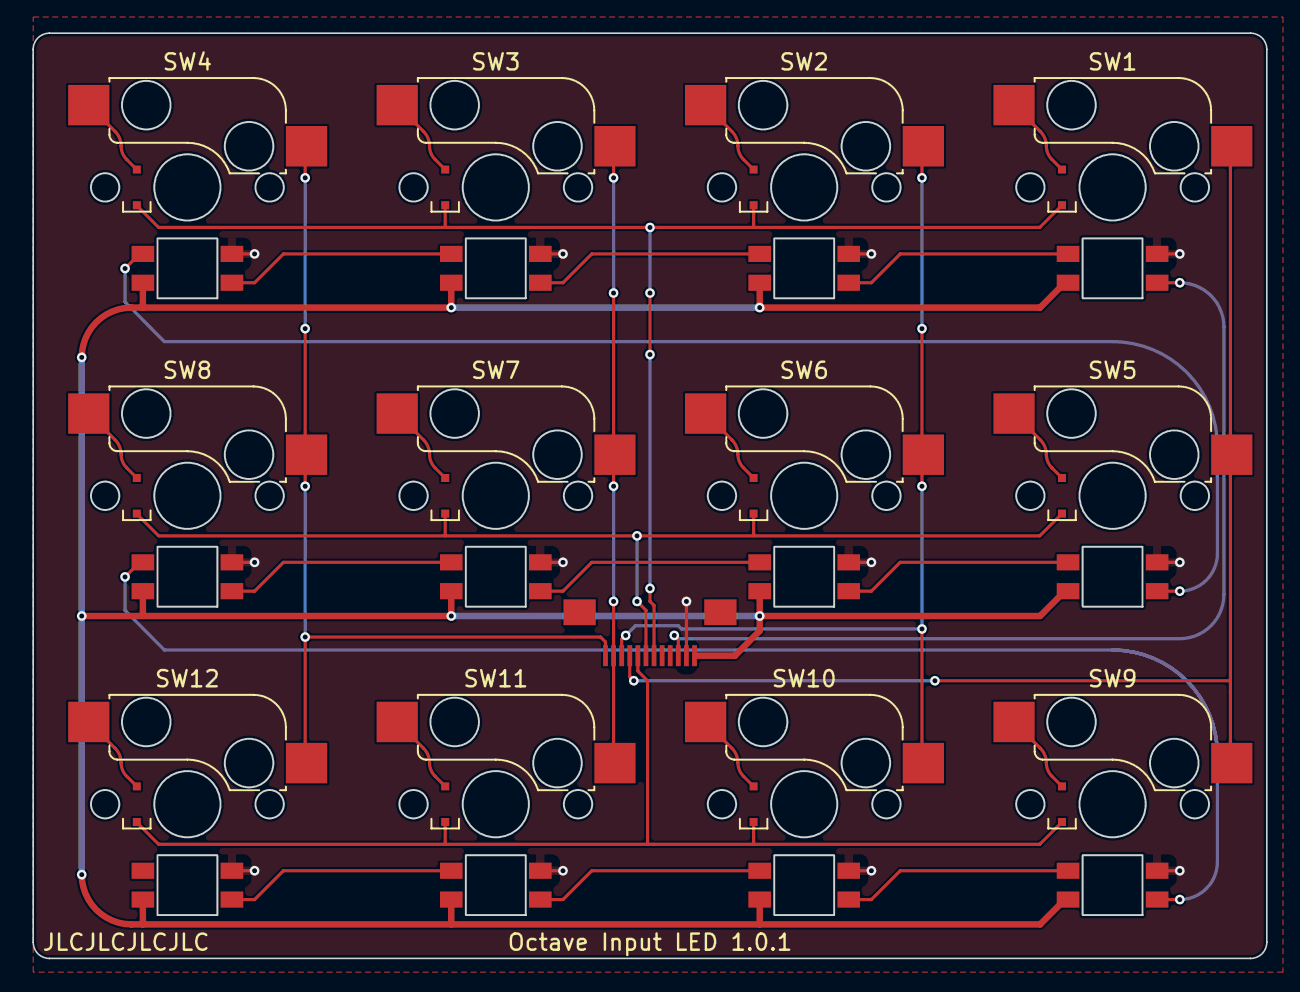
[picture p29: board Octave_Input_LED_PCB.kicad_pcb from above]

Board: 2 copper layers, 76.2 x 57.2 mm, 37 parts (0 on the bottom side), 33 nets.

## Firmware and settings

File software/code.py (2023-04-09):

import collections
import math
import random
import time

import board
import digitalio
import usb_hid
from adafruit_hid.consumer_control import ConsumerControl
from adafruit_hid.consumer_control_code import ConsumerControlCode
from adafruit_hid.keyboard import Keyboard
from adafruit_hid.keyboard_layout_us import KeyboardLayoutUS
from adafruit_hid.keycode import Keycode
from adafruit_hid.mouse import Mouse
from neopixel import NeoPixel

from octave_pcb.key_event import KeyEvent, KeyEventPlanner
from octave_pcb.key_matrix import KeyMatrix


class CodeType:
  KEYBOARD = 0
  MOUSE_MOVE = 1
  MOUSE_BUTTON = 2
  CONSUMER_CONTROL = 3
  LAYER_MOMENTRY = 4


KeyAssignment = collections.namedtuple('KeyAssignment', ['type', 'code'])
LambdaAssignment = collections.namedtuple('LambdaAssignment', ['on_press', 'on_release'])


SCAN_KEY_MATRIX_INTERVAL = 0.01
PIXELS_INTERVAL = 0.05
PIXELS_PATTEN_COUNT = 3

pixels_pattern = 0
pixels_frame_count = 0
pixels_target = [[0.0, 0.0, 0.0] for _ in range(12)]
pixels_current = [[0.0, 0.0, 0.0] for _ in range(12)]


def next_pixels_pattern():
  global pixels_pattern
  global pixels_frame_count
  pixels_pattern = (pixels_pattern + 1) % PIXELS_PATTEN_COUNT
  pixels_frame_count = 0


KEY_MAP_LAYERS = [
    [
        KeyAssignment(CodeType.KEYBOARD, Keycode.F1),
        KeyAssignment(CodeType.KEYBOARD, Keycode.F2),
        KeyAssignment(CodeType.KEYBOARD, Keycode.F3),
        KeyAssignment(CodeType.KEYBOARD, Keycode.F4),
        KeyAssignment(CodeType.KEYBOARD, Keycode.F5),
        KeyAssignment(CodeType.KEYBOARD, Keycode.F6),
        KeyAssignment(CodeType.KEYBOARD, Keycode.F7),
        KeyAssignment(CodeType.KEYBOARD, Keycode.F8),
        KeyAssignment(CodeType.KEYBOARD, Keycode.SHIFT),
        KeyAssignment(CodeType.KEYBOARD, Keycode.CONTROL),
        KeyAssignment(CodeType.KEYBOARD, Keycode.ESCAPE),
        KeyAssignment(CodeType.LAYER_MOMENTRY, None),
    ],
    [
        KeyAssignment(CodeType.KEYBOARD, Keycode.F9),
        KeyAssignment(CodeType.KEYBOARD, Keycode.F10),
        KeyAssignment(CodeType.KEYBOARD, Keycode.F11),
        KeyAssignment(CodeType.KEYBOARD, Keycode.F12),
        KeyAssignment(CodeType.CONSUMER_CONTROL, ConsumerControlCode.VOLUME_DECREMENT),
        KeyAssignment(CodeType.CONSUMER_CONTROL, ConsumerControlCode.VOLUME_INCREMENT),
        KeyAssignment(CodeType.CONSUMER_CONTROL, ConsumerControlCode.REWIND),
        KeyAssignment(CodeType.CONSUMER_CONTROL, ConsumerControlCode.FAST_FORWARD),
        KeyAssignment(CodeType.KEYBOARD, Keycode.SHIFT),
        KeyAssignment(CodeType.KEYBOARD, Keycode.CONTROL),
        LambdaAssignment(next_pixels_pattern, None),
        None,
    ],
]


def update_pixels_according_to_key_presses(pixels, are_keys_pressed):
  for i in range(len(pixels)):
    if are_keys_pressed[i]:
      pixels[i] = [
          (255, 0, 0),
          (255, 128, 0),
          (255, 255, 0),
          (128, 255, 0),
          (0, 255, 0),
          (0, 255, 128),
          (0, 255, 255),
          (0, 128, 255),
          (0, 0, 255),
          (128, 0, 255),
          (255, 0, 255),
          (255, 0, 128),
      ][i]
    elif pixels[i] != (0, 0, 0):
      pixels[i] = (
          math.floor(pixels[i][0] * 0.8),
          math.floor(pixels[i][1] * 0.8),
          math.floor(pixels[i][2] * 0.8))


def update_pixels_transition(pixels):
  global pixels_frame_count
  global pixels_target
  global pixels_current
  if pixels_frame_count % 60 == 0:
    pixels_target[0][random.randint(0, 2)] = 0.5
    pixels_target[0][random.randint(0, 2)] = 0
    pixels_target[0][random.randint(0, 2)] = 0
    pixels_target[0][random.randint(0, 2)] = 1
  pixels_current[0][0] = pixels_current[0][0] * 0.97 + pixels_target[0][0] * 0.03
  pixels_current[0][1] = pixels_current[0][1] * 0.97 + pixels_target[0][1] * 0.03
  pixels_current[0][2] = pixels_current[0][2] * 0.97 + pixels_target[0][2] * 0.03
  for i in range(len(pixels)):
    pixels[i] = (
        math.floor(pixels_current[0][0] * 32),
        math.floor(pixels_current[0][1] * 32),
        math.floor(pixels_current[0][2] * 32))
  pixels_frame_count += 1
  pixels_frame_count = pixels_frame_count % 60


def update_pixels_random(pixels):
  global pixels_frame_count
  global pixels_target
  global pixels_current
  for i in range(len(pixels)):
    if pixels_frame_count % 60 == 0:
      pixels_target[i][random.randint(0, 2)] = 0.5
      pixels_target[i][random.randint(0, 2)] = 0
      pixels_target[i][random.randint(0, 2)] = 0
      pixels_target[i][random.randint(0, 2)] = 1
    pixels_current[i][0] = pixels_current[i][0] * 0.9 + pixels_target[i][0] * 0.1
    pixels_current[i][1] = pixels_current[i][1] * 0.9 + pixels_target[i][1] * 0.1
    pixels_current[i][2] = pixels_current[i][2] * 0.9 + pixels_target[i][2] * 0.1
    pixels[i] = (
        math.floor(pixels_current[i][0] * 32),
        math.floor(pixels_current[i][1] * 32),
        math.floor(pixels_current[i][2] * 32))
  pixels_frame_count += 1
  pixels_frame_count = pixels_frame_count % 60


if __name__ == '__main__':
  key_matrix = KeyMatrix()
  key_event_planners = [KeyEventPlanner() for _ in range(len(key_matrix.row_ios) * len(key_matrix.col_ios))]

  cpu_pixpower = digitalio.DigitalInOut(board.NEOPIX_POWER)
  cpu_pixpower.switch_to_output(True, digitalio.DriveMode.PUSH_PULL)
  cpu_pix = NeoPixel(board.NEOPIX, 1, auto_write=True)
  cpu_pix[0] = (0, 0, 2)

  pixels = NeoPixel(board.GPIO20, 12, auto_write=False)
  pixels.show()
  pixels_target = [[0.0, 0.0, 0.0] for _ in range(12)]
  pixels_current = [[0.0, 0.0, 0.0] for _ in range(12)]
  pixels_frame_count = 0
  pixels_pattern = 0

  # Sleep for a bit to avoid a race condition on some systems
  time.sleep(1)

  while True:
    try:
      keyboard = Keyboard(usb_hid.devices)
      keyboard_layout = KeyboardLayoutUS(keyboard)
      mouse = Mouse(usb_hid.devices)
      consumer_control = ConsumerControl(usb_hid.devices)
      cpu_pix[0] = (0, 2, 2)

      key_map_layer = 0
      pressed_keys = [None for _ in range(len(key_event_planners))]

      scan_key_matrix_timing = time.monotonic()  # For debounce
      pixels_timing = time.monotonic()  # For animation
      while True:
        current_time = time.monotonic()

        if current_time >= scan_key_matrix_timing:
          are_keys_pressed = key_matrix.scan_matrix()
          for i, key_event_planner in enumerate(key_event_planners):
            key_event = key_event_planner.make_event(
                current_time, are_keys_pressed[i])
            if key_event == KeyEvent.PRESS:
              # print(f"""pressed : {i}""")
              pressed_keys[i] = KEY_MAP_LAYERS[key_map_layer][i]
              key_assignment = pressed_keys[i]
              if key_assignment is None:
                pass
              elif isinstance(key_assignment, KeyAssignment):
                if key_assignment.type == CodeType.LAYER_MOMENTRY:
                  key_map_layer = 1
                elif key_assignment.type == CodeType.KEYBOARD:
                  keyboard.press(key_assignment.code)
                elif key_assignment.type == CodeType.MOUSE_MOVE:
                  mouse.move(**key_assignment.code)
                elif key_assignment.type == CodeType.MOUSE_BUTTON:
                  mouse.press(key_assignment.code)
                elif key_assignment.type == CodeType.CONSUMER_CONTROL:
                  consumer_control.press(key_assignment.code)
              elif isinstance(key_assignment, LambdaAssignment) and key_assignment.on_press is not None:
                key_assignment.on_press()
            elif key_event == KeyEvent.LONG_PRESS:
              # print(f"""pressed : {i}""")
              key_assignment = pressed_keys[i]
              if key_assignment is None:
                pass
              elif isinstance(key_assignment, KeyAssignment):
                if key_assignment.type == CodeType.LAYER_MOMENTRY:
                  pass
                elif key_assignment.type == CodeType.KEYBOARD:
                  # print(f"""pressed : {i}""")
                  keyboard.press(key_assignment.code)
                elif key_assignment.type == CodeType.MOUSE_MOVE:
                  # print(f"""pressed : {i}""")
                  mouse.move(**key_assignment.code)
            elif key_event == KeyEvent.RELEASE:
              # print(f"""released: {i}""")
              key_assignment = pressed_keys[i]
              pressed_keys[i] = None
              if key_assignment is None:
                pass
              elif isinstance(key_assignment, KeyAssignment):
                if key_assignment.type == CodeType.LAYER_MOMENTRY:
                  key_map_layer = 0
                elif key_assignment.type == CodeType.KEYBOARD:
                  keyboard.release(key_assignment.code)
                elif key_assignment.type == CodeType.MOUSE_BUTTON:
                  mouse.release(key_assignment.code)
                elif key_assignment.type == CodeType.CONSUMER_CONTROL:
                  consumer_control.release()
              elif isinstance(key_assignment, LambdaAssignment) and key_assignment.on_release is not None:
                key_assignment.on_release()
          scan_key_matrix_timing += SCAN_KEY_MATRIX_INTERVAL
          if scan_key_matrix_timing <= current_time:
            scan_key_matrix_timing = current_time + SCAN_KEY_MATRIX_INTERVAL

        if current_time >= pixels_timing:
          should_show_pixels = True
          if pixels_pattern == 0:
            prev_pixels = [pixel for pixel in pixels]
            update_pixels_according_to_key_presses(pixels, are_keys_pressed)
            should_show_pixels = not all(map(lambda i: pixels[i] == prev_pixels[i], range(12)))
          elif pixels_pattern == 1:
            update_pixels_transition(pixels)
          elif pixels_pattern == 2:
            update_pixels_random(pixels)

          if should_show_pixels:
            pixels.show()
          pixels_timing += PIXELS_INTERVAL
          if pixels_timing <= current_time:
            pixels_timing = current_time + PIXELS_INTERVAL

    except Exception:
      cpu_pix[0] = (0, 0, 2)
      time.sleep(3)

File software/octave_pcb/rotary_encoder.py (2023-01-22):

import board
import digitalio


class RotaryEncoder:

  class Status():
    IDLE = 0
    CW_BEGINNING = 1
    CW_CANDIDATE = 2
    CCW_BEGINNING = 3
    CCW_CANDIDATE = 4

  def __init__(self):
    self.io_a = digitalio.DigitalInOut(board.GPIO3)
    self.io_a.switch_to_input(digitalio.Pull.UP)
    self.io_b = digitalio.DigitalInOut(board.GPIO2)
    self.io_b.switch_to_input(digitalio.Pull.UP)

    self.previous_signals = None
    self.state = RotaryEncoder.Status.IDLE

  def deinit(self):
    self.io_a.deinit()
    self.io_b.deinit()

  def detect_direction(self):
    detected_direction = 0
    signals = [self.io_a.value, self.io_b.value]
    if signals != self.previous_signals:
      #   0     1     2     3     0'
      # [H,H] [L,H] [L,L] [H,L] [H,H] => CW
      # [H,H] [H,L] [L,L] [L,H] [H,H] => CCW
      if signals == [True, True]:
        if self.state == RotaryEncoder.Status.CW_CANDIDATE:
          detected_direction = 1
        elif self.state == RotaryEncoder.Status.CCW_CANDIDATE:
          detected_direction = -1
        self.state = RotaryEncoder.Status.IDLE
      elif signals == [False, True]:
        if self.state == RotaryEncoder.Status.IDLE:
          self.state = RotaryEncoder.Status.CW_BEGINNING
        elif self.state == RotaryEncoder.Status.CW_CANDIDATE:
          self.state = RotaryEncoder.Status.CW_BEGINNING
        elif self.state == RotaryEncoder.Status.CCW_BEGINNING:
          self.state = RotaryEncoder.Status.CCW_CANDIDATE
      elif signals == [True, False]:
        if self.state == RotaryEncoder.Status.IDLE:
          self.state = RotaryEncoder.Status.CCW_BEGINNING
        elif self.state == RotaryEncoder.Status.CW_BEGINNING:
          self.state = RotaryEncoder.Status.CW_CANDIDATE
        elif self.state == RotaryEncoder.Status.CCW_CANDIDATE:
          self.state = RotaryEncoder.Status.CCW_BEGINNING
        elif signals == [False, False]:
          if self.state == RotaryEncoder.Status.CW_BEGINNING:
            self.state = RotaryEncoder.Status.CW_CANDIDATE
          elif self.state == RotaryEncoder.Status.CCW_BEGINNING:
            self.state = RotaryEncoder.Status.CCW_CANDIDATE
    self.previous_signals = signals
    return detected_direction

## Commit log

2022-02-23 Study key matrix
    [key-matrix.kicad_sch]
2022-02-26 New add KiCad project to prepare footprints
    [Untitled.kicad_sch]
2022-02-26 Add hot swap socket footprint
2022-02-27 Update Hot_Swap_Socket_CPG151101S11.scad
    Modify pin height
2022-02-27 Add hot swap socket 3D shape
2022-02-27 Pin my KiCad library to the project
2022-02-28 Add hot swap socket symbol
2022-03-02 New add KiCad project
    [Octave_Input_PCB.kicad_pcb, Octave_Input_PCB.kicad_sch]
2022-03-02 Add key matrix schematic
    [Octave_Input_PCB.kicad_sch]
2022-03-02 Connect D
    [Octave_Input_PCB.kicad_pcb]
2022-03-02 Update schematic and PCB
    [Octave_Input_PCB.kicad_pcb, Octave_Input_PCB.kicad_sch]
2022-03-02 Create incremental encoder footprint
2022-03-05 Update schematic
    [Octave_Input_PCB.kicad_pcb, Octave_Input_PCB.kicad_sch]
2022-03-06 Schematic rev.1 is available
    [Octave_Input_PCB.kicad_pcb, Octave_Input_PCB.kicad_sch, Untitled.kicad_sch]
2022-03-06 Reset PCB tracks
    [Octave_Input_PCB.kicad_pcb, Octave_Input_PCB.kicad_sch]
2022-03-06 Update PCB tracks
    [Octave_Input_PCB.kicad_pcb]
2022-03-06 Update schematic
    Since label C hid GND in the net list, remove label C and simply connect to GND.
    [Octave_Input_PCB.kicad_pcb, Octave_Input_PCB.kicad_sch]
2022-03-06 Update PCB
    [Octave_Input_PCB.kicad_pcb]
2022-03-09 Add PCB 3D image
    [Octave_Input_PCB.kicad_pcb]
2022-03-21 Add enclosure 3D model (Base only)
    [Octave_Enclosure-Base.step, Octave_Enclosure.FCStd]
2022-03-21 Update enclosure 3D model
    Modify base, and add cover
    [Octave_Enclosure-Base.step, Octave_Enclosure-Cover.step, Octave_Enclosure-Cover.stl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]
2022-03-28 Update PCB 3D image
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2022-03-29 Add first prototype software, test SW14
2022-03-30 Change the height of the enclosure base to fit the USB cable
    [Octave_Enclosure-Base.step, Octave_Enclosure.FCStd]
2022-04-02 Update prototype issues
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2022-04-08 Add: Assign rotary encoder operation to mouse wheel operation
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2022-04-10 Change key map (prototype)
2022-04-13 Update schematic
    Close some issues:
    - Fix U1 symbol
    - Change R1 and R3 value
    [Octave_Input_PCB.kicad_sch]
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2022-04-14 Fix pin assignment of RP2040 footprint
2022-04-15 Close first prototype, start second prototype
2022-04-30 [WIP] Update schematic
    [Octave_Input_PCB.kicad_pcb, Octave_Input_PCB.kicad_sch]
2022-05-04 Add RP2040 #schematic
    [Octave_Input_PCB.kicad_pcb, Octave_Input_PCB.kicad_sch]
2022-05-05 Renumber the capacitors #schematic
    [Octave_Input_PCB.kicad_pcb, Octave_Input_PCB.kicad_sch]
2022-05-05 Change the diode footprint for the key matrix from SOD-323 to SOD-323F
    [Octave_Input_PCB.kicad_pcb, Octave_Input_PCB.kicad_sch]
2022-05-06 Improve hot swap socket footprint
    [Octave_Input_PCB.kicad_pcb]
2022-05-06 [WIP] Update schematic and PCB
    [Octave_Input_PCB.kicad_pcb, Octave_Input_PCB.kicad_sch]
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2022-05-06 Rename usb c footprint
2022-05-06 [WIP] Update schematic and PCB
    Add a USB-C connector, but using the Molex 1054500101 makes routing very difficult.
    [Octave_Input_PCB.kicad_pcb, Octave_Input_PCB.kicad_sch]
2022-05-07 Change the USB-C connector to HRO TYPE-C-31-M-12
    [Octave_Input_PCB.kicad_pcb, Octave_Input_PCB.kicad_sch]
2022-05-14 [WIP] Update PCB
    [Octave_Input_PCB.kicad_pcb]
2022-05-17 Add crystal resonator
    [Octave_Input_PCB.kicad_pcb, Octave_Input_PCB.kicad_sch]
2022-05-29 Complete schematic and PCB (rev.5.0.0)
    [Octave_Input_PCB.kicad_pcb, Octave_Input_PCB.kicad_sch]
2022-05-30 Fix C13 and C14 value, improve Y1 pattern
    [Octave_Input_PCB.kicad_pcb, Octave_Input_PCB.kicad_sch]
2022-05-30 Add pull-up for QSPI_SS_N
    [Octave_Input_PCB.kicad_pcb, Octave_Input_PCB.kicad_sch]
2022-05-30 Change C1 and C2 value
    [Octave_Input_PCB.kicad_pcb, Octave_Input_PCB.kicad_sch]
2022-05-30 Rename footprint of tactile switch
    [Octave_Input_PCB.kicad_pcb, Octave_Input_PCB.kicad_sch]
2022-06-13 Oops, fix schematics of SW21 and SW22
    [Octave_Input_PCB.kicad_pcb, Octave_Input_PCB.kicad_sch]
2022-06-13 Improve schematic and PCB
    [Octave_Input_PCB.kicad_pcb, Octave_Input_PCB.kicad_sch]
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2022-06-16 Add link to CircuitPython
2022-06-18 Add BOM of PCB
2022-06-19 Add a link to the CircuitPython 7.3.x code
2022-06-19 [WIP] Add software for prototype-2
2022-06-19 Add a link to the protoype-2-pcb tag
2022-06-19 Add a issue of prototype-2 (solved)
2022-06-19 Add an issue of prototype-2 (solved)
    [Octave_Input_PCB.kicad_pcb, Octave_Input_PCB.kicad_sch]
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2022-07-31 Add prototype-2 issues
2022-08-12 Update README.md
    Update the link to latest CircuitPython
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2022-09-10 Remove unused symbols on schematic
    [Octave_Input_PCB.kicad_sch]
2022-09-11 Separate the PCB into two parts: UI and MPU
    [Octave_Input_PCB.kicad_sch]
2023-01-03 Update Octave_Input_PCB.kicad_pcb
    Adjust clearance
    [Octave_Input_PCB.kicad_pcb]
2023-01-07 Add plate design
    [Octave_Plate.kicad_pcb]
2023-01-08 Update plate design
    [Octave_Plate.kicad_pcb]
2023-01-08 Fix Edge.Cuts of PCB
    [Octave_Input_PCB.kicad_pcb]
2023-01-08 Fix footprint of J2 and J3
    [Octave_Input_PCB.kicad_pcb]
2023-01-09 Change plate design
    [Octave_Plate.kicad_pcb]
2023-01-09 Modify PCB and plate
    [Octave_Input_PCB.kicad_pcb, Octave_Plate.kicad_pcb]
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2023-01-22 Fix BOM for prototype-2
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2023-01-22 Customize key bindings for testing prototype-3
    [code.py]
2023-01-23 Remove old enclosure design
    [Octave_Enclosure-Base.step, Octave_Enclosure-Cover.step, Octave_Enclosure-Cover.stl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]
2023-02-11 Add enclosure photo and stl files of it
    [Octave_Enclosure-Case.stl, Octave_Enclosure-Top Frame.stl]
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2023-02-26 Update the version of CircuitPython used to 8.0.3
    Update software dependencies
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2023-03-16 Create KiCad project for LEDs under keys by copying Input PCB
    [Octave_Input_LED_PCB.kicad_pcb, Octave_Input_LED_PCB.kicad_sch]
2023-03-16 Remove CPU PCB from Input LED PCB
    [Octave_Input_LED_PCB.kicad_pcb, Octave_Input_LED_PCB.kicad_sch]
2023-03-16 Add footprint of WS2812B-Mini with inverted placement
    [Octave_Input_LED_PCB.kicad_pcb, Octave_Input_LED_PCB.kicad_sch]
2023-03-19 Improve edge cuts of WS2812B-Mini (Inverted)
    [Octave_Input_LED_PCB.kicad_pcb]
2023-03-19 Route PCB
    [Octave_Input_LED_PCB.kicad_pcb]
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2023-03-21 Modify background color of the upgrade PCB schematic SVG image
2023-03-21 Wait for my PCB ordered
    [Octave_Input_LED_PCB.kicad_pcb]
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2023-04-09 Improve footprint of WS2812B-Mini_Inverted
    [Octave_Input_LED_PCB.kicad_pcb]
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

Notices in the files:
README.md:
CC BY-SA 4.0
